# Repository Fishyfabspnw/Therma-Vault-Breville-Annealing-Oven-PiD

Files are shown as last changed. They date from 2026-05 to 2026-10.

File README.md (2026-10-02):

# ThermaVault PID

**Industrial-style PID-controlled annealing oven conversion based on a Breville convection oven platform.**

ThermaVault PID is a documentation-first appliance conversion project focused on creating a more stable, serviceable, and repeatable annealing oven for engineering plastics used in 3D printing.

The build replaces the factory appliance timer/control behavior with an industrial PID controller, solid state relay heater control, high-temperature sensing, upgraded insulation, and a more modular electronics layout.

> **Status:** Active build / documentation in progress  
> **Platform:** Breville convection oven conversion  
> **Use case:** Controlled annealing cycles for engineering plastics

<p align="center">
  ThermaVault PID prototype enclosure and control layout
</p>

<p align="center">
  <em>ThermaVault PID prototype enclosure and control layout</em>
</p>

---

## Table of Contents

- [Project Goals](#project-goals)
- [System Overview](#system-overview)
- [Documentation](#documentation)
- [Bill of Materials](#bill-of-materials)
- [Photos](#photos)
- [Community Builds](#community-builds)
- [Safety Notice](#safety-notice)
- [License](#license)

---

## Project Goals

ThermaVault is being built as a compact process oven platform with a focus on:

- Stable annealing temperatures
- Reduced thermal overshoot
- Better chamber temperature consistency
- Programmable ramp/soak heat cycles
- Serviceable wiring and component layout
- Industrial-style process control hardware
- Improved insulation for long-duration heat stability
- Reusable appliance platform for future refinement

This is not meant to be a quick “add a PID and call it good” project. The goal is to build a cleaner, safer, better-documented oven conversion that can be maintained, upgraded, and understood later.

---

## System Overview

At a high level, the oven uses a PID controller to read chamber temperature and control the heating elements through a properly rated AC solid state relay.

The factory convection fan is retained so the oven can continue circulating hot air through the chamber. Temperature feedback is handled by a high-temperature sensor mounted for chamber/process temperature control.

<p align="center">
  PID controller
  SSR hardware
</p>

---

## Documentation

| Document | Purpose |
|---|---|
| [Bill of Materials](./BOM.md) | Current parts list, links, quantities, and notes |
| [Safety Notes](./SAFETY.md) | Mains voltage, SSR, fuse, and thermal safety notes |
| [CAD Models](./CAD%20Models/) | CAD files, printable parts, and SVG artwork |
| [Tear Down Photo Log](./Project%20Documentation/Tear%20Down%20Overview.md) | Documentation of the factory oven teardown process |
| [Build Log](./Project%20Documentation/Build%20Log.md) | Ongoing build progression, thermal modifications, wiring integration, and control system development |
| [Community Builds](./Project%20Documentation/Community%20Builds/README.md) | Adaptations of the ThermaVault concept to other oven models |

---

## Bill of Materials

The BOM has been moved to a dedicated file so it can expand without cluttering the main README.

See: **[BOM.md](./BOM.md)**

---

## Photos

Current photo documentation:

- [Tear Down Photo Log](./Project%20Documentation/Tear%20Down%20Overview.md)
- [Build Log](./Project%20Documentation/Build%20Log.md)

---

## Community Builds

ThermaVault now has a dedicated **community build library** for adaptations of the project to other oven models.

Current documented adaptation:

- **[Breville BOV650 community build](./Project%20Documentation/Community%20Builds/BOV650/README.md)** — BOV650 conversion based on the ThermaVault guide, including a model-specific front control panel.

<p align="center">
  <a href="./Project%20Documentation/Community%20Builds/BOV650/README.md">
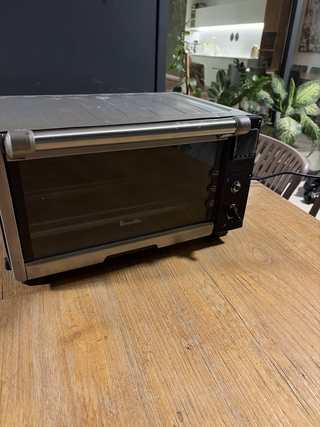
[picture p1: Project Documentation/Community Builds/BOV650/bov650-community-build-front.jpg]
Breville BOV650 community ThermaVault build
    
  </a>
</p>

Browse all adaptations and the folder format here: **[Community Builds Index](./Project%20Documentation/Community%20Builds/README.md)**

---

## Safety Notice

> **Warning:** This project involves mains AC voltage, high temperatures, resistive heating elements, appliance modification, and long-duration unattended heat risk. Mistakes can cause electric shock, fire, equipment damage, or injury.

Minimum safety expectations:

- Use properly rated fuses or breakers.
- Maintain chassis ground continuity.
- Use high-temperature wire inside hot zones.
- Mount the SSR to a correctly sized heat sink.
- Keep low-voltage and mains-voltage wiring separated.
- Do not bypass factory thermal safety devices unless they are replaced with equal or better protection.
- Verify wiring with a meter before applying power.
- Perform initial heat tests attended and away from flammable material.

Read the full safety page before copying any part of this build: **[SAFETY.md](./SAFETY.md)**

---

## License

This project is licensed under the **GNU GPL v3.0 License**.

---

## FishyFabsPNW

Designed, built, and documented by **FishyFabsPNW**.

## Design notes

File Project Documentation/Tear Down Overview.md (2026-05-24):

# Breville BOV800XL Tear Down Documentation

## Oven Platform

Breville BOV800XL Smart Oven  
https://www.breville.com/en-us/product/bov800

This document covers the teardown and inspection process of the Breville BOV800XL convection oven platform used for the ThermaVault PID conversion project.

The teardown process is intended to:

- Understand the factory heater layout
- Identify factory thermal protection hardware
- Inspect airflow routing
- Document internal wiring layout
- Remove the factory control system
- Prepare the platform for PID conversion

<p align="center">
  
  
</p>

---

## Initial Disassembly

The outer shell is secured using multiple perimeter screws around the chassis.

Disassembly process:

1. Remove all visible perimeter screws.
2. Remove the hidden screws located underneath near the control board area.
3. Slide the shell rearward toward the back of the oven.
4. Lift the shell upward to fully remove the outer housing.

---

## Initial Observations

Once opened, several major factory systems become visible:

- Lower heater banks
- Factory convection fan
- Thermal protection devices
- Factory control PCB
- Internal airflow routing
- Heater wiring layout

<p align="center">
  Internal oven layout
</p>

---

## Factory Heating System

The factory heating system consists of:

- Multiple upper heating elements
- Lower heating element banks
- Individually grouped heater circuits
- Convection-assisted airflow circulation

The heater groups appear to be separated into:

- Upper heater group(s)
- Lower heater group(s)

<p align="center">
  Factory heater layout
</p>

---

## Factory Thermal Protection

The factory oven contains integrated thermal protection devices within the heater system wiring.

These devices are intended to:

- Interrupt power during overheating conditions
- Protect internal wiring and electronics
- Reduce fire risk
- Prevent unsafe chamber temperatures

The factory thermal protection system remains an important consideration during the ThermaVault PID conversion.

---

## Factory Parts Diagram Verification

The factory thermal fuse assembly was verified using the Breville BOV800XL parts diagram and component reference documentation.

The identified thermal protection assembly appears to match the factory-installed safety configuration used within the original heater circuit.

---

## Factory Thermal Fuse Reference

<p align="center">
  Factory thermal fuse reference
</p>

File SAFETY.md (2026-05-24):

# ThermaVault PID — Safety Notes

## Warning

This project involves:

- Mains AC voltage
- High current heater loads
- Elevated temperatures
- Appliance modification
- Fire risk
- Long-duration heat cycles

If you are not comfortable working around mains wiring and electrical safety practices, do not attempt this build.

---

## Electrical Safety

### Grounding

The oven chassis must remain properly grounded.

Do not remove or defeat chassis grounding connections.

---

### Fuse / Breaker Protection

Incoming AC power should be protected by a properly sized fuse or breaker.

Protection should be installed before downstream electronics and heater circuits.

---

### SSR Safety

Solid state relays generate heat and can fail.

Minimum recommendations:

- Use a properly rated SSR
- Mount the SSR to a heat sink
- Ensure airflow if enclosure temperatures rise
- Verify wiring polarity and load routing
- Avoid counterfeit SSRs

---

### Wire Selection

Use properly rated high-temperature wire inside heated zones.

Do not use standard low-temperature hookup wire near heating elements.

---

### Wire Routing

Separate:

- Low-voltage sensor wiring
- PID control wiring
- High-voltage AC heater wiring

This helps reduce electrical noise and improves safety/serviceability.

---

## Thermal Safety

Recommended:

- Independent thermal cutoff
- Attended first heat tests
- Non-flammable mounting surface
- Clearance from combustible materials

Never leave early test cycles unattended.

---

## Build Responsibility

This repository is for documentation and educational purposes.

Anyone reproducing this project assumes responsibility for their own wiring, safety validation, thermal testing, and electrical compliance.

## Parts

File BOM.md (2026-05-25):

# ThermaVault PID — Bill of Materials

> BOM is actively changing as the project evolves.

---

## Bill of Materials (BOM)

| Category | Component | Model / Type | Qty | Notes | Link |
|---|---|---|---:|---|---|
| Electronics | PID Controller | Novus N20K48 | 1 | Main process controller with ramp/soak support | [Novus](https://www.novusautomation.com/site/default.asp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) |
| Electronics | Solid State Relay | Celduc SO943460 40A | 1 | Main heater switching SSR | [DigiKey](https://www.digikey.com/en/products/detail/celduc/SO943460/14311190) |
| Electronics | SSR Heat Sink | Generic aluminum SSR heat sink | 1 | Required for SSR thermal management | [Amazon](https://www.amazon.com/dp/B091HQL9TM) |
| Electronics | Temperature Sensor | PT100 RTD | 1 | Chamber temperature sensing | [Amazon](https://www.amazon.com/dp/B0FS7LJR8T) |
| Electronics | Main Power Switch | Illuminated rocker switch | 1 | Main system power switching | [Amazon](https://www.amazon.com/dp/B000HEIY1Q?ref=ppx_yo2ov_dt_b_fed_asin_title) |
| Electronics | Fuse / Breaker | Panel-mount protection device | 1 | Required line protection | [Amazon](https://www.amazon.com/dp/B08RBLZF9L?ref=ppx_yo2ov_dt_b_fed_asin_title) |
| Electronics | Terminal Blocks | WAGO / terminal strip | As needed | AC power distribution and wiring management | [Amazon](https://www.amazon.com/Compact-Splicing-Connector-Assortment-221-2401/dp/B0CJ5QF3VX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) |
| Thermal | Ceramic Fiber Insulation | High-temp insulation | 2 Boxes | Improves chamber thermal stability and efficiency | [Amazon](https://www.amazon.com/dp/B0CNQZJXVP) |
| Thermal | High-Temp Wire | Mica / fiberglass insulated wire | 16ft | Used near high-temperature heater zones | [Amazon](https://www.amazon.com/dp/B0D8BBSKHM) |
| Printed Parts | WAGO 221 DIN Rail Holder | Printable DIN rail mount | 2 Printed | Mounting solution for WAGO 221 connectorsn | [MakerWorld](https://makerworld.com/en/models/2337616-wago-ac-distribution-block-din-rail-mout-l-n#profileId-2554998) |
| Printed Parts | WAGO 221 DIN Rail Holder | Printable DIN rail mount | 2 Printed | Mounting solution for WAGO 221 connectors | [MakerWorld](https://makerworld.com/en/models/2597414-wago-221-holder-for-din-rail-2-3-5-way#profileId-2866148) |
---

## Recommended SSR Manufacturers

| Manufacturer | Notes |
|---|---|
| Celduc | Industrial-grade SSR option |
| Sensata / Crydom | Reliable industrial SSRs |
| Panasonic Electric Works | Compact SSR options |
| Crouzet | Industrial automation hardware |

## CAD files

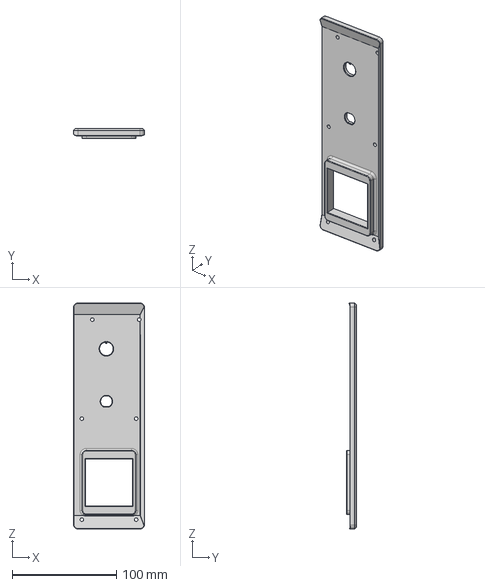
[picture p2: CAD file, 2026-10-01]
CAD Models/FacePlate_BOV650.step
68.0 x 10.0 x 217.0 mm

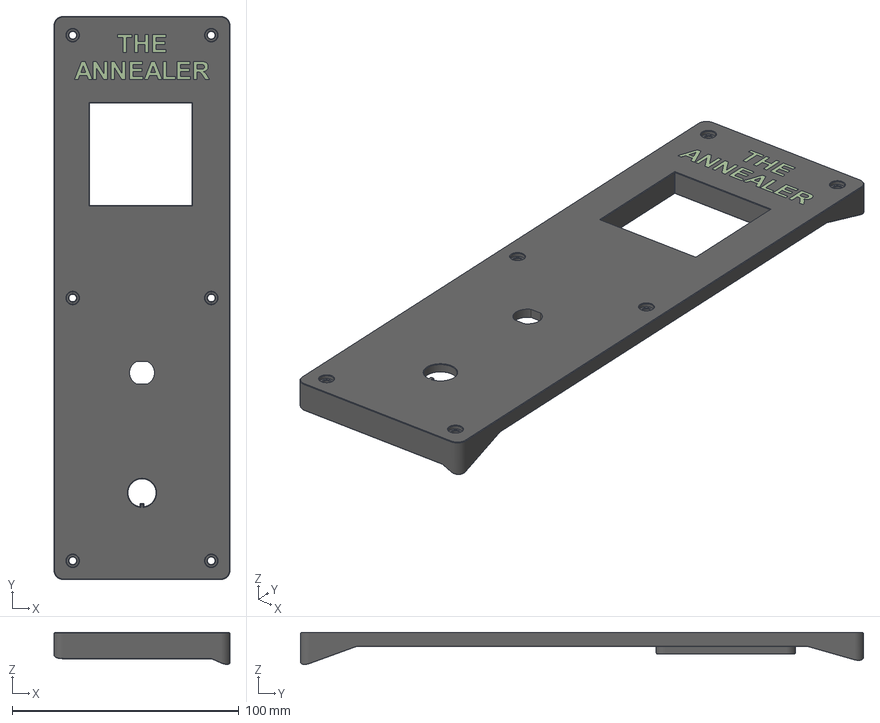
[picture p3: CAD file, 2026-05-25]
CAD Models/STL's/Faceplate.3mf
77.7 x 248.5 x 14.1 mm

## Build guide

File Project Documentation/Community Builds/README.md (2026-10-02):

# ThermaVault Community Builds

This directory is for builds that use the **ThermaVault PID project as a starting point** but adapt it to a different oven model, enclosure, control-panel layout, or hardware arrangement.

Keeping each adaptation in its own folder makes it possible to add more models without turning the main project README into one long photo log.

---

## Build Index

| Oven / Platform | Build page | Model-specific files |
|---|---|---|
| **Breville BOV650** | [View BOV650 build](./BOV650/README.md) | [FacePlate_BOV650.step](../../CAD%20Models/FacePlate_BOV650.step) |

---

## Folder Layout

Each community build should use its own model folder:

```text
Project Documentation/
└── Community Builds/
    ├── README.md
    ├── BUILD_TEMPLATE.md
    ├── BOV650/
    │   ├── README.md
    │   ├── bov650-community-build-front.jpg
    │   ├── bov650-community-build-controls.jpg
    │   └── bov650-community-build-angle.jpg
    └── <NEXT_MODEL>/
        ├── README.md
        └── photos...
```

Model-specific CAD can stay in the main **[CAD Models](../../CAD%20Models/)** directory so printable/CAD files remain easy to find from one place.

---

## Adding Another Build

1. Copy **[BUILD_TEMPLATE.md](./BUILD_TEMPLATE.md)** into a new folder named after the oven model.
2. Rename it to `README.md`.
3. Add the build photos to that same folder.
4. Add any model-specific CAD to the main `CAD Models/` directory.
5. Add the new model to the **Build Index** table above.
6. Add a short link under **Community Builds** in the root project README if you want it featured there.

---

## Important

Community adaptations may use different dimensions, wiring layouts, heating elements, controls, thermal protection, or factory hardware than the original ThermaVault build. Treat each build as a reference for that specific platform and verify dimensions, electrical ratings, grounding, fusing, and thermal safety before applying it to another oven.

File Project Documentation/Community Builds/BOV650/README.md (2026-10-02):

# Breville BOV650 Community Build

This build was created by a community member using the **ThermaVault PID build guide as the starting point** and adapting the design to a **Breville BOV650**.

The BOV650 chassis uses a different front/control-area layout than the original project, so this version uses a model-specific control faceplate while keeping the same overall ThermaVault concept.

---

## Photos

### Front / overall view

<p align="center">
  Breville BOV650 ThermaVault community build front view
</p>

### Control panel

<p align="center">
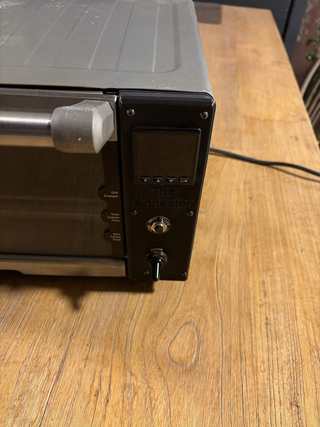
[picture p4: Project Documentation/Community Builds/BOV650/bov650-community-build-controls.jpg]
Breville BOV650 ThermaVault community build control panel
  
</p>

### Angled view

<p align="center">
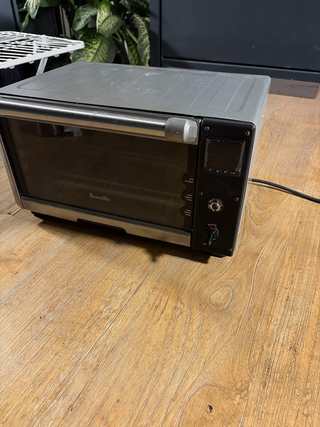
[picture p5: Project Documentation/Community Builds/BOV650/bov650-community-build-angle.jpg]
Breville BOV650 ThermaVault community build angled view
  
</p>

---

## BOV650-Specific CAD

The model-specific front control plate is available here:

**[FacePlate_BOV650.step](../../../CAD%20Models/FacePlate_BOV650.step)**

---

## Notes

- Platform: **Breville BOV650**
- Based on: **ThermaVault PID build guide**
- Adaptation type: Model-specific enclosure/control-panel conversion
- The photos above document a community implementation rather than the original reference oven.

Because factory construction and revisions can vary, verify all dimensions against the actual oven before manufacturing parts. Electrical ratings, grounding, fusing, thermal cutoffs, wire temperature ratings, and SSR/heater sizing also need to be checked for the specific unit being converted.

---

[← Back to Community Builds](../README.md)

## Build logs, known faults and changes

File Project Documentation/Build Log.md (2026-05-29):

# ThermaVault PID — Build Log

## Overview

This document tracks the progression of the ThermaVault PID annealing oven conversion project.

The purpose of this build log is to document major design changes, thermal modifications, wiring improvements, and hardware integration throughout the development process.

The project is centered around converting a Breville convection oven into a more stable and serviceable PID-controlled process oven for annealing engineering plastics.

---

# Factory Control Panel Removal and Faceplate Development

The original Breville front control panel assembly was removed early in the build process to allow integration of a dedicated industrial PID controller and externalized control hardware.

The factory faceplate was retained during the tear down phase so it could be repurposed into a new control layout instead of starting from a completely blank panel.

<p align="center">
  Factory control panel
</p>

<p align="center">
  <em>Original Breville control panel removed during tear down for conversion into the new ThermaVault PID control interface.</em>
</p>

A custom replacement faceplate was then designed and fabricated to integrate the industrial PID controller and external power controls into a cleaner and more serviceable layout.

The redesigned panel relocates critical process controls outside the primary heated cavity while replacing the original consumer appliance interface with a more industrial control system architecture.

The faceplate assembly was CAD-modeled around the factory oven chassis geometry, existing mounting locations, and component clearance constraints.

<p align="center">
  ThermaVault faceplate CAD front view
</p>

<p align="center">
  <em>Initial CAD layout for the custom ThermaVault PID control faceplate.</em>
</p>

<br>

<p align="center">
  ThermaVault faceplate CAD secondary view
</p>

<p align="center">
  <em>CAD development showing controller positioning, switch integration, and chassis fitment planning.</em>
</p>

## N20K48 PID Controller Retention

During final faceplate fitment, the N20K48 PID controller was held in place by the rear green terminal block once the controller was seated in the panel opening.

The retaining clips that came with the PID controller were not used in this build. With the custom faceplate layout and rear clearance constraints, the terminal block provided the practical retention point for the controller body.

> **Fitment note:** Before final assembly, verify that the PID controller is fully seated in the faceplate, the green terminal block is secure, and the controller cannot shift forward or backward under normal handling.

## Fuse and Switch Clearance Modification

During test fitting, the original gray plastic structure behind the faceplate interfered with the added fuse holder and power switch. The extra plastic had to be removed so both components could sit fully into the panel without being forced or misaligned.

The first image shows the original gray plastic ribbing before modification. The second image shows the area after the plastic was broken out and cleared for the fuse and switch body.

<p align="center">
  Gray plastic structure behind the faceplate before fuse and switch clearance modification
</p>

<p align="center">
  <em>Original gray plastic behind the faceplate that interfered with the fuse holder and switch fitment.</em>
</p>

<p align="center">
  Gray plastic removed from behind the faceplate to allow fuse holder and switch clearance
</p>

<p align="center">
  <em>Plastic cleared from the rear of the faceplate so the fuse holder and power switch could seat properly.</em>
</p>

---

# Chamber Sealing and Thermal Preparation

High-temperature RTV sealant was applied around exposed seams and panel joints to reduce uncontrolled airflow leakage and improve thermal retention.

Additional ceramic insulation was added around exposed cavities and structural gaps throughout the chamber shell.

Particular attention was given to:

- Heater compartment gaps
- Rear panel seams
- Wire pass-through locations
- Structural openings around the shell

The goal of this stage was to improve chamber consistency and reduce unnecessary heat loss.

<p align="center">
  RTV sealing process
</p>

<p align="center">
<i>Initial chamber sealing and ceramic insulation integration around exposed shell gaps and rear panel seams.</i>
</p>

<p align="center">
  Upper heater sealing
</p>

<p align="center">
<i>Additional RTV sealing work performed around upper heater routing and structural panel seams.</i>
</p>

<p align="center">
  Kwool ceramic insulation added around the oven shell
</p>

<p align="center">
  <em>Kwool ceramic insulation added around the oven shell to improve heat retention and reduce heat loss through the outer body.</em>
</p>

---

## Sensor Routing

The RTD PT100 probe was routed through the factory wire pass-through location using a 1/8" NPT compression fitting. This kept the sensor installation clean while avoiding the need for additional holes in the oven chassis.

<p align="center">
  ThermaVault PT100 sensor routing
</p>

<p align="center">
  <em>PT100 RTD routing through the factory chassis pass-through using high-temperature sleeving and a 1/8&quot; NPT fitting.</em>
</p>

---

## Convection Fan Calibration

During initial testing, the factory convection fan assembly produced a noticeable harmonic hum. The fan was still functional, but the blade assembly had enough runout and imbalance to create vibration and resonance during operation.

To correct this, the fan blades were manually trued using a dial indicator. Each blade was checked by rotating the fan by hand, identifying high and low spots, and carefully adjusting the blade position until the runout was reduced.

<p align="center">
  ThermaVault convection fan blade calibration
</p>

<p align="center">
  <em>Dial indicator setup used to measure fan blade runout and correct blade alignment before final fan testing.</em>
</p>

### Calibration Steps

- Mounted a dial indicator against the outer edge of the fan blades
- Rotated the fan assembly by hand to check blade-to-blade consistency
- Identified high and low spots in the blade path
- Adjusted individual blades in small increments
- Rechecked the fan until the runout and visible wobble were reduced

### Before Calibration

Before adjustment, the fan had visible runout and produced a stronger harmonic hum during operation. This made the fan sound rougher than expected and showed that the blade assembly was not spinning evenly.

https://github.com/user-attachments/assets/86a4d50e-11a0-4eb5-be31-e4b34c51b753

### After Calibration

After truing the blades, the fan ran noticeably smoother with less vibration and a lower audible hum. This should help reduce resonance in the oven shell during long annealing cycles.

https://github.com/user-attachments/assets/ccb41f80-d16f-4f0b-a22a-a5547bd761ed

### Result

- Reduced fan vibration
- Lower harmonic hum during operation
- Smoother convection fan rotation
- Less resonance transferring into the oven shell

---

# DIN Rail and Wiring Distribution

A compact DIN rail assembly was added to improve wiring organization and modularity.

WAGO lever connectors were mounted using DIN rail carrier adapters to create a cleaner and more serviceable wiring distribution layout.

Compared to direct point-to-point splicing, the DIN rail layout significantly improves:

- Wiring organization
- Future expandability
- Service access
- Troubleshooting capability
- Component replacement simplicity

The terminal distribution layout was designed to keep the wiring compact while maintaining separation between different circuit groups.

<p align="center">
<i>Initial DIN rail and WAGO terminal distribution layout integrated into the rear electronics area.</i>
</p>

<p align="center">
  Updated wiring distribution
</p>

<p align="center">
<i>Refined wiring layout with improved routing organization and terminal distribution structure.</i>
</p>

---

## SSR Installation and Heat Sink Mounting

The solid state relay was mounted to an aluminum heat sink using thermal paste between the SSR and the heat sink surface. The thermal paste improves heat transfer from the SSR into the heat sink during heater cycling.

After the SSR was attached to the heat sink, the heat sink assembly was bolted to the metal shell of the oven. This gives the SSR a solid mechanical mounting point and allows the oven shell to act as additional thermal mass.

This location keeps the SSR close to the heater wiring path while still keeping it mounted outside the primary heated chamber area.

<p align="center">
  SSR mounted to heat sink and bolted to the oven shell
</p>

<p align="center">
  <em>SSR mounted with thermal paste to a heat sink, then bolted to the oven shell for improved heat dissipation and serviceable wiring layout.</em>
</p>

<p align="center">
  Additional view of SSR heat sink mounting and rear wiring layout
</p>

<p align="center">
  <em>Additional rear view showing the SSR heat sink location, nearby WAGO distribution blocks, and wiring path around the heater control area.</em>
</p>

> **Build note:** The SSR should be mounted tightly against the heat sink with thermal paste applied between the two surfaces. Wiring should be kept clear of the heat sink body and high-voltage terminals.

---

## Wiring Inspection Before Shell Reassembly

Before reinstalling the outer shell, the wiring layout was checked over with the oven still open. This is the best time to verify that all high-voltage connections are seated, all terminals are tight, and nothing can rub against sharp sheet-metal edges once the cover is installed.

This inspection step is especially important because once the shell is back on, access to the SSR, WAGO distribution blocks, sensor routing, and heater wiring becomes much more limited.

<p align="center">
  Open rear wiring inspection before reinstalling the oven shell
</p>

<p align="center">
  <em>Final open-shell wiring check before reinstalling the oven cover.</em>
</p>

<p align="center">
  Additional wiring inspection view before reinstalling the oven shell
</p>

<p align="center">
  <em>Additional inspection angle showing the rear wiring, terminal layout, and clearance checks before the shell was reinstalled.</em>
</p>

### Pre-Reassembly Checks

- Confirm all WAGO levers are fully closed
- Verify all screw terminals are tight
- Check that high-temperature wire is used anywhere exposed to heat
- Keep mains-voltage wiring separated from sensor and control wiring where possible
- Make sure wires cannot contact heater elements, sharp sheet metal, or the convection fan
- Confirm the SSR and heat sink are securely mounted
- Verify chassis ground continuity before powering the oven again

> **Safety note:** Do not reinstall the shell until the wiring has been visually inspected and verified with a meter where needed. This build uses mains AC voltage, so any loose connection or misplaced wire can become a serious shock or fire hazard.

---

## Shell Reassembly and Control Box Fitment

After the wiring inspection was complete, the outer shell was reinstalled around the oven body. During reassembly, the mounting locations were checked carefully so the shell could be seated without pinching wires or forcing the panels out of alignment.

The rear control box also required extra reach to reinstall the screws cleanly. A drill extension was used to access the recessed fasteners and tighten the control box back into place after the shell was fitted.

<p align="center">
  Pointing to oven shell mounting location during reassembly
</p>

<p align="center">
  <em>Checking shell mounting locations before reinstalling the outer cover.</em>
</p>

<p align="center">
  Second shell mounting location reference during oven reassembly
</p>

<p align="center">
  <em>Additional mounting point reference used while lining up the oven shell.</em>
</p>

<p align="center">
  Drill extension needed to reach recessed control box screws
</p>

<p align="center">
  <em>Drill extension used to reach the recessed screws for the rear control box.</em>
</p>

<p align="center">
  Using drill extensions to reinstall the oven control box screws
</p>

<p align="center">
  <em>Reinstalling the control box screws with extensions after the shell was positioned.</em>
</p>

<p align="center">
  Oven shell reinstalled and ThermaVault PID powered on
</p>

<p align="center">
  <em>Shell reinstalled and the oven powered on for the next stage of testing.</em>
</p>

### Reassembly Notes

- Verified shell mounting points before tightening screws
- Checked that the shell did not pinch or pull on wiring
- Used drill extensions to reach recessed control box fasteners
- Confirmed the rear electronics area remained serviceable after reassembly
- Powered the oven on after the shell was reinstalled for the next round of functional testing

---

## Controller Setup, First PID Tune, and First Annealing Cycle

With the oven reassembled and powered on, the next stage was setting up the PID controller through the phone app and preparing the oven for its first controlled heat cycle.

The controller was connected through the app so the process temperature, setpoint, output behavior, and tuning status could be monitored without relying only on the front panel display. This made it easier to watch the oven during early testing and confirm that the controller was responding correctly.

### Initial Controller Setup

The first setup pass focused on confirming the basics before running a full annealing cycle:

- Verified that the PT100 temperature reading was stable and believable at room temperature
- Confirmed the controller was in automatic control mode, not manual output mode
- Checked that the SSR output switched the heating elements on and off correctly
- Verified that the convection fan operated as expected
- Set a conservative test temperature before moving into higher-temperature annealing profiles
- Watched the app display to confirm that the process value followed the setpoint correctly

This step was important because manual output mode can drive the heating elements continuously. For normal annealing use, the controller needs to regulate temperature automatically through the SSR.

### First PID Autotune

After basic operation was confirmed, the first PID autotune was started with the oven empty and under direct supervision. The goal of the autotune was to let the controller learn how the modified oven responds to heat input, insulation, convection airflow, and thermal lag.

During tuning, the controller cycles the heater output and watches how the chamber temperature rises, overshoots, falls, and stabilizes. From that response, it calculates new PID values for proportional, integral, and derivative control.

The first tune is not treated as the final tune forever. It is a baseline tune for the current oven configuration. Any major change to insulation, sensor placement, heater wiring, fan behavior, or chamber load may require tuning again.

### First Annealing Test

Once the controller completed its first tune, the oven was used for an initial annealing test. This first run was treated as a validation cycle rather than a production cycle.

The purpose of the first annealing run was to confirm:

- The oven could reach the target temperature without uncontrolled overshoot
- The controller could hold a stable temperature after heat soak
- The SSR and heat sink remained stable during repeated heater cycling
- The convection fan continued to move air through the chamber
- The wiring and shell remained mechanically stable after heating
- The chamber cooled down normally after the cycle

For the first real material test, the oven should be watched closely from heat-up through cooldown. The goal is not just to make the plastic hot. The goal is to prove that the converted oven behaves predictably enough to become a repeatable annealing tool.

### First-Cycle Notes

- Run the first cycle empty or with a low-risk test part before trusting critical parts
- Stay with the oven during the first full heat cycle
- Watch for smell, smoke, wire movement, abnormal fan noise, or unstable temperature behavior
- Confirm the SSR heat sink temperature stays reasonable during cycling
- Let the oven cool down naturally before opening it aggressively or removing parts
- Record the first usable temperature profile so future cycles can be compared against it

> **Build note:** The first PID tune and first annealing cycle are part of commissioning the oven. They should be treated as controlled testing, not normal unattended operation.

---

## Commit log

2026-05-20 Revise README for ThermaVault PID project
    Updated project details and structure in README.md to enhance clarity and provide comprehensive information about the ThermaVault PID project.
2026-05-20 Revise README for clarity and conciseness
    Updated terminology for clarity and improved safety instructions. Removed sections on heater system and airflow system for conciseness.
2026-05-20 Update README to clarify PID control features
2026-05-22 Fix links in Bill of Materials section
    Updated links in the Bill of Materials section for clarity.
2026-05-24 Add dedicated BOM documentation
2026-05-24 Clean up BOM layout and embed links directly in tables
2026-05-24 Add images to Build Log for ThermaVault PID
2026-05-24 Update Build Log by removing reference note
    Removed original Breville front control assembly note.
2026-05-25 Revise Build Log for Custom Faceplate Development
    Updated the documentation for custom faceplate development, including CAD layouts and current control system features.
2026-05-25 Add CAD models section to README
2026-05-25 Add CAD Models folder
2026-05-25 Simplify CAD Models reference in README
2026-05-25 Create STL's
2026-05-28 Add SSR heat sink mounting section to build log
2026-05-28 Add additional SSR heat sink installation photo
2026-05-28 Clean up convection fan calibration section
2026-05-28 Add wiring inspection note before shell reassembly
2026-05-28 Move convection fan calibration earlier in build log
2026-05-28 Add additional wiring inspection photo
2026-05-28 Add shell reassembly and first power-on section
2026-05-29 Add N20K48 PID mounting note
2026-10-01 FacePlate_BOV650
    FacePlate for Breville BOV650
    [FacePlate_BOV650.step]
